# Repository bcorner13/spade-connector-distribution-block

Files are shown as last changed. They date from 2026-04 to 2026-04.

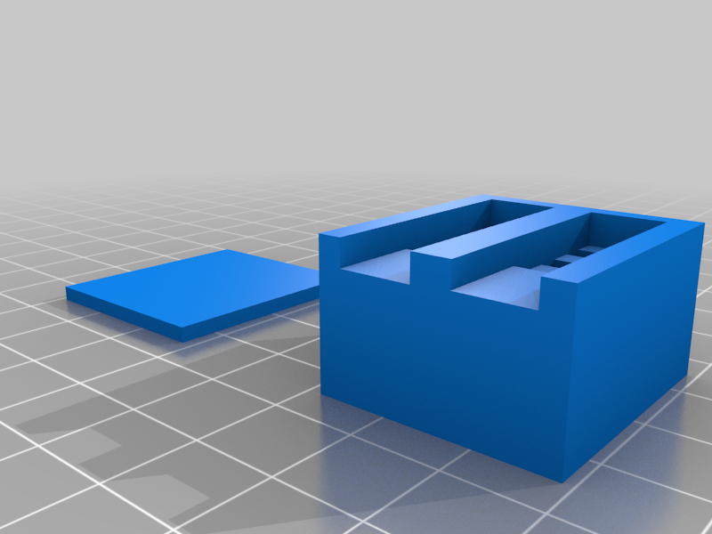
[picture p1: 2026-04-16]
images/Distribution_Block.png

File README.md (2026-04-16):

# QD_Bar — Parametric Spade Connector Distribution Block

Fully parametric 6-slot spade connector distribution bar for a Daytona Coupe gauge harness.
Two bars are printed — one **power**, one **ground**.

**Power bar slot assignment:**
| Slot | Connection |
|---|---|
| 1 | Harness power feed |
| 2 | Tach |
| 3 | Gauge white 1 |
| 4 | Gauge white 2 |
| 5 | Gauge white 3 |
| 6 | Gauge white 4 |

The ground bar mirrors the same 6-slot layout.

---

## Files

| File | Description |
|---|---|
| `files/QD_Bar.FCStd` | Assembly + VarSet (all params live here) |
| `Distribution Block.FCStd` | Parametric bar body |
| `Lid.FCStd` | Slide-in rail cover with clip tab |
| `cad/Mount.FCStd` | L-bracket standoff for gauge mounting |
| `cad/varsets/qd_bar_vars.json` | Canonical parameter values |

---

## Parametric Usage

1. Open `files/QD_Bar.FCStd` in FreeCAD 1.1+
2. Edit `VarSet` — change **NumSlots**, **SlotSpacing**, etc.
3. FreeCAD recomputes automatically — slots repopulate via LinearPattern

Key parameters:
- `NumSlots` — number of connector slots (default: 6)
- `SlotSpacing` — center-to-center spacing in mm (default: 9.5)
- `SlotWidth` — slot opening width in mm (default: 6.6 for 6.3mm spade + 0.3 clearance)
- `BodyHeight` — overall bar height (default: 22mm)
- `Width` — bar depth (default: 30mm)
- `MountSpan` — gauge stud center-to-center for bracket (default: 120mm)

All derived lengths (bar `Length`, etc.) update automatically from these values.

---

## Print Settings

| Setting | Value |
|---|---|
| Material | PLA or PETG |
| Layer height | 0.2 mm |
| Nozzle | 0.4 mm |
| Walls/perimeters | 2 |
| Infill | 20% |
| Orientation | Long axis horizontal; rails printed vertically |

### Tolerances
- `ClearanceSide` (default 0.1mm) — lid rail side play; increase if rails bind
- `ClipClearance` (default 0.05mm) — clip tab engagement gap; increase for looser snap

Adjust per filament shrinkage. PETG typically needs +0.05–0.1mm additional clearance.

### Recommended chamfers/fillets (apply in slicer or model)
- 0.3mm chamfer on groove/rail entry mouth
- 0.5mm fillet on inner slot corners

---

## Mount Bracket

The `Mount.FCStd` L-bracket mounts to the outer M4/5-32" studs on a pair of gauges.
- Stud slots: 5mm wide × 10mm long (fits M4, allows fine alignment)
- Stud span: 120mm center-to-center (set `MountSpan` in VarSet to adjust)
- Riser height: 25mm (clears wiring with 5mm margin over 20mm wire stack)
- Inward shelf: bar drops into retention slots on the shelf top face

---

## Running Tests Locally

Requires FreeCAD 1.1+ with the **FreeCAD MCP Server** addon installed and running (TCP port 9876).

**Prerequisites:**
1. FreeCAD 1.1 installed
2. [FreeCAD MCP Server](https://github.com/your-org/freecad-mcp-server) addon installed and enabled inside FreeCAD
3. These documents open in FreeCAD:
   - `files/QD_Bar.FCStd`
   - `Distribution Block.FCStd`
   - `Lid.FCStd`
   - `cad/Mount.FCStd`

The test scripts connect to the FreeCAD MCP Server via TCP (`FREECAD_MCP_HOST` / `FREECAD_MCP_PORT`, default `127.0.0.1:9876`).

```bash
make test           # full MCP verification suite
make export-stl     # export Distribution_Block, Lid, Mount to files/*.stl
make regen-variants # fuzz NumSlots 2–10, save screenshots to mcp-tests/output/
```

---

## CI

The GitHub Actions workflow (`.github/workflows/cad-ci.yml`) runs **static checks** on every push and PR:
- Required files present (`.FCStd`, `Makefile`, `qd_bar_vars.json`)
- `cad/varsets/qd_bar_vars.json` is valid JSON
- All `mcp-tests/*.py` scripts pass syntax check

Full MCP verification (`make test`) requires FreeCAD 1.1 + MCP addon and runs locally.

---

## Credits

Based on [Spade Connector Distribution Block by frankjay](https://www.thingiverse.com/thing:4854104) (Thingiverse).

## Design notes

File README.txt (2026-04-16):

Spade Connector Distribution Block by frankjay on Thingiverse: https://www.thingiverse.com/thing:4854104

Summary:
For connecting multiple devices to one power/signal source.Add female spade connectors in top slots, space for soldering together beneath, solder protruding male spade connectors out bottom slots.When using crimp connectors recommend soldering them as well.Combine female connector to a roughly 3 inch length of bare wire and insert into rearmost slot, bend the wire forward so it sticks out the front/bottom notches then combine 2 more female connectors with 1" of bare wire, insert and solder together, repeat for other side... glue on base and add male connectors as inputs.PLA plastic stands up well to the heat of soldering, push joints flat to fit into space and use superglue to enclose with base.I have not yet tested this version of the design but i'm confident it is the best one so fari will have photos of the assembly steps uploaded shortly

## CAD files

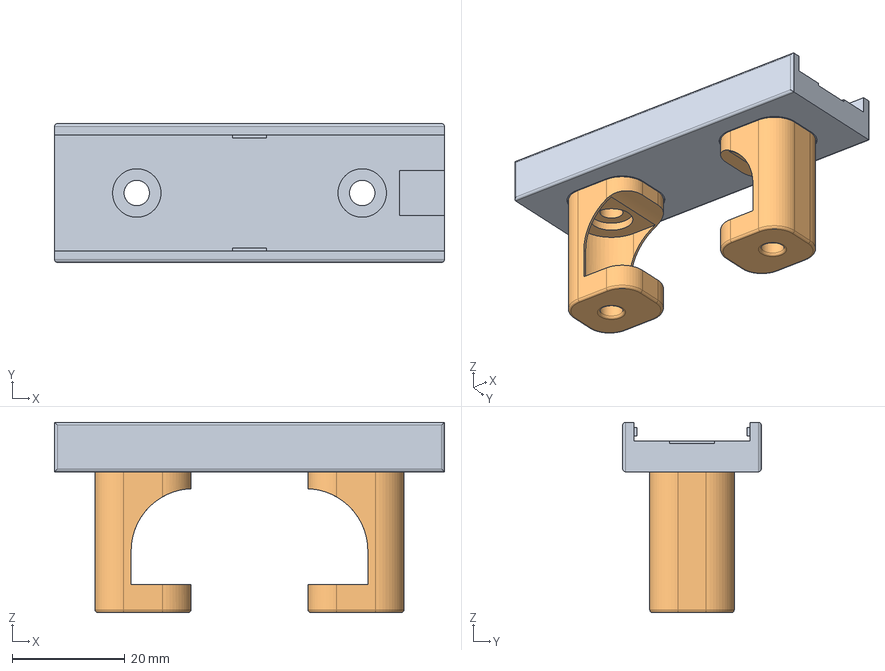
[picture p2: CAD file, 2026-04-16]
cad/Mount.FCStd
69.2 x 24.6 x 33.8 mm
Body_Bracket
Body_Posts

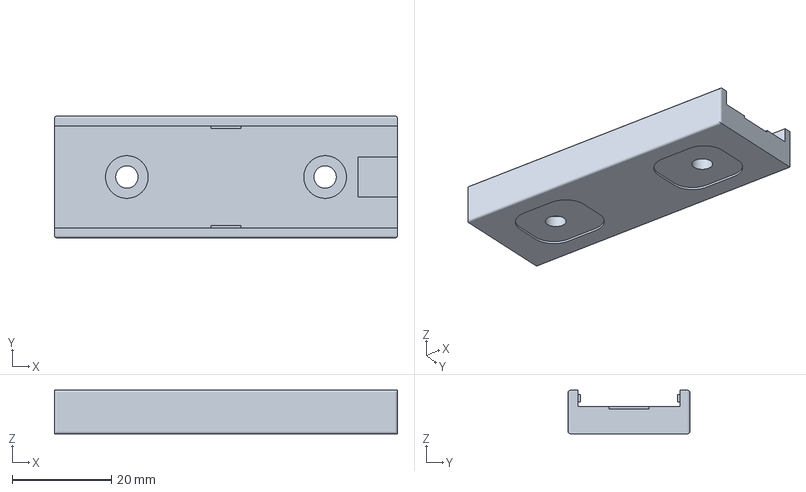
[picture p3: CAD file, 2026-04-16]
files/Mount_Bracket.3mf
69.2 x 24.6 x 8.80 mm

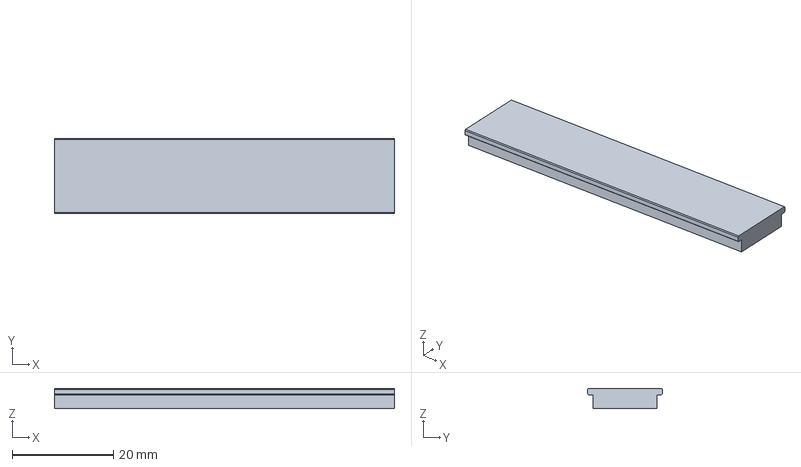
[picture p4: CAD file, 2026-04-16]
Lid.FCStd
67.2 x 14.8 x 4.00 mm

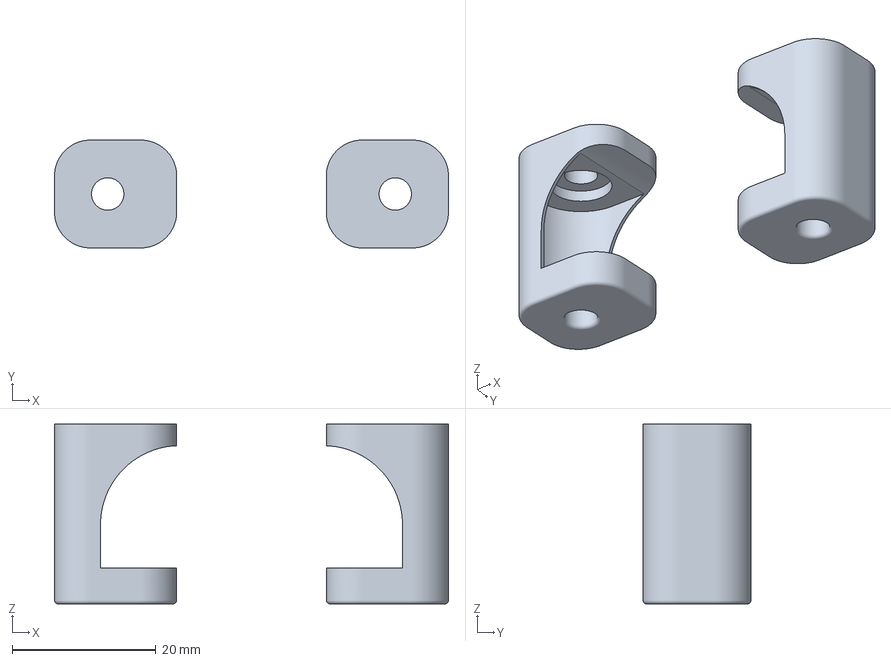
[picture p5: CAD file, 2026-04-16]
files/Mount_Posts.3mf
54.8 x 15.0 x 25.0 mm

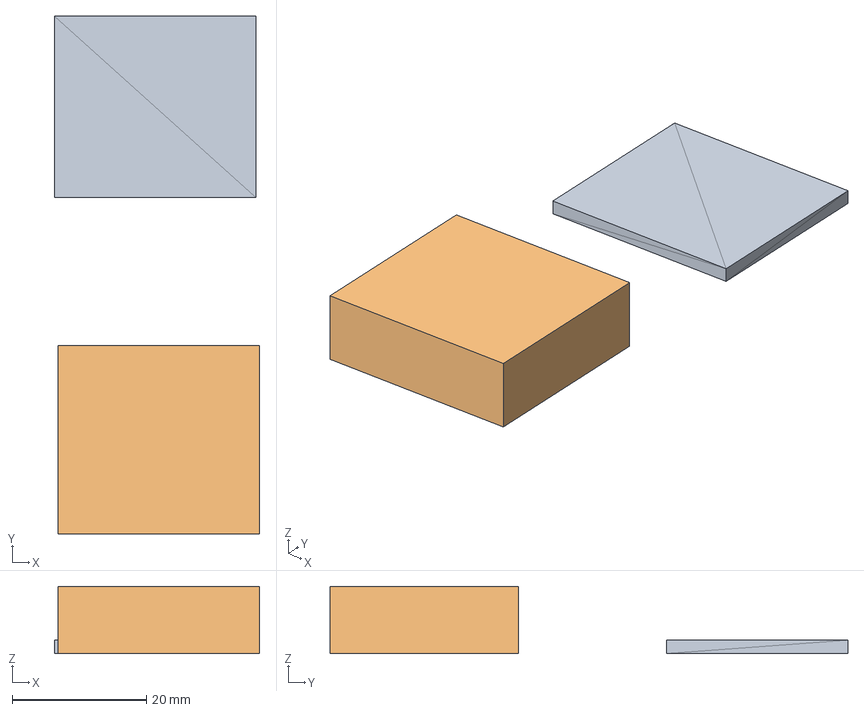
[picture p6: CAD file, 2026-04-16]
QD_Bar.FCStd
30.5 x 77.0 x 10.0 mm
Cover

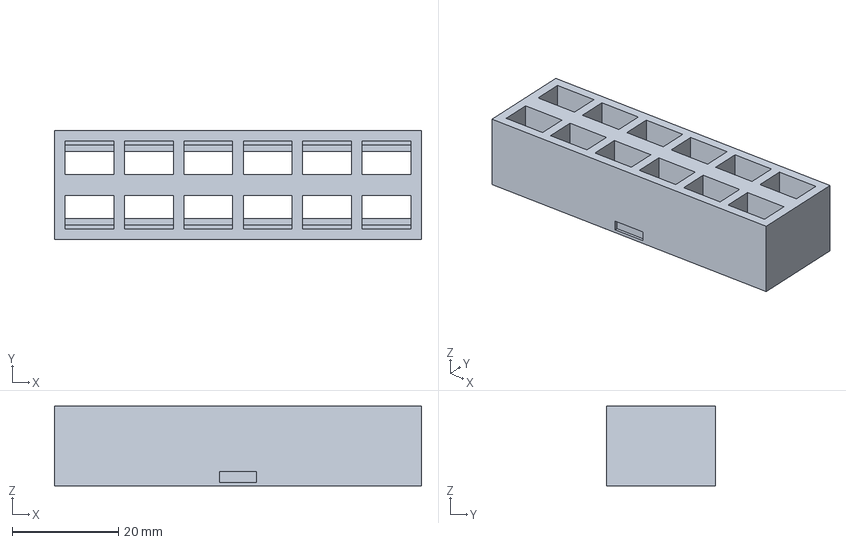
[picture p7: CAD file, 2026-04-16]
Distribution Block.FCStd
69.2 x 20.6 x 15.0 mm

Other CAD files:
Params.FCStd
PowerDistribution.FCStd
files/Distribution_Block.3mf
files/Distribution_Block.stl
files/Lid.3mf
files/Lid.stl
files/Mount_Bracket.stl
files/Mount_Posts.stl
files/PowerDistribution.3mf
files/QD_Bar.FCStd
